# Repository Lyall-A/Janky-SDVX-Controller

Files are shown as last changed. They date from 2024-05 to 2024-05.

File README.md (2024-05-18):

# Janky SDVX Controller
A worse version of the [Pocket-SDVX-Pico-v4](https://github.com/speedypotato/Pocket-SDVX-Pico-v4) with no RGB

## Firmware
* [Leonardo Firmware](./Leonardo%20Firmware): Firmware for ATmega32u4 microcontrollers (Leonardo/Pro Micro)
* [Pico Firmware](./Pico%20Firmware): Firmware for RP2040 microcontrollers (Pico)
* [Unsupported Board Firmware](./Unsupported%20Board%20Firmware): Firmware for other microcontrollers. Uses Serial instead of HID (**PLEASE DO NOT USE THIS**)

## Parts
* x2 Encoders ([PEC16-2015F-N0024](https://mou.sr/3JNRuk8))
* x7 Switches ([Gateron Red](https://mechboards.co.uk/products/gateron-red?variant=41710358888653))
* x1 ATmega32u4 or RP2040 microcontroller ([Raspberry Pi Pico](https://thepihut.com/products/raspberry-pi-pico), [Pro Micro](https://www.aliexpress.com/item/32808519179.html))
* x1 [1U Keycap](https://www.aliexpress.com/item/1005004064331568.html)
* x4 [1.5U Keycaps](https://www.aliexpress.com/item/1005004784994416.html)
* x2 [2U Keycaps](https://www.aliexpress.com/item/1005004784994416.html)

## 3D Printed Parts
* x1 [Case (15mm Thickness)](./Models/STL/Case%20(15mm%20Thickness).stl) or [Case (25mm Thickness)](./Models/STL/Case%20(25mm%20Thickness).stl)
* x1 [Case Top (14.4mm Switch Holes)](./Models/STL/Case%20Top%20(14.4mm%20Switch%20Holes).stl) or [Case Top (14mm Switch Holes)](./Models/STL/Case%20Top%20(14mm%20Switch%20Holes).stl)
* x2 [Knobs (22mm)](./Models/STL/Knob%20(22mm).stl) or [Knobs (25mm)](./Models/STL/Knob%20(25mm).stl)
* x1 [1U Keycap](https://www.printables.com/model/440477-keycaps-for-pico-sdvx-controller)
* x4 [1.5U Keycaps](https://www.printables.com/model/440477-keycaps-for-pico-sdvx-controller)
* x2 [2U Keycaps](https://www.printables.com/model/440477-keycaps-for-pico-sdvx-controller)

## Pictures
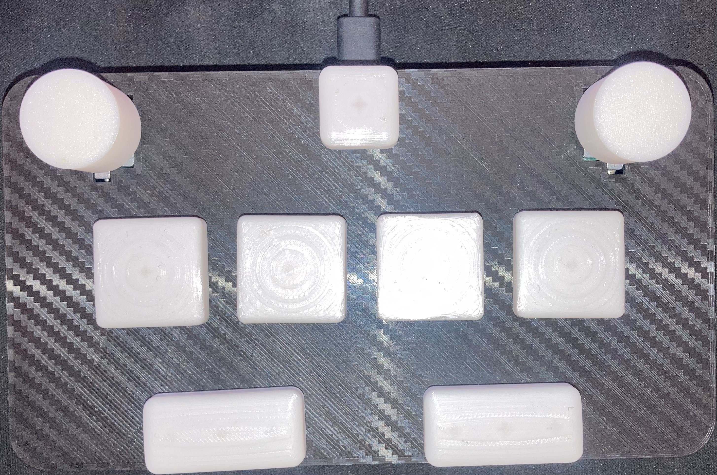
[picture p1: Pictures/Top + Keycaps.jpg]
Top + Keycaps

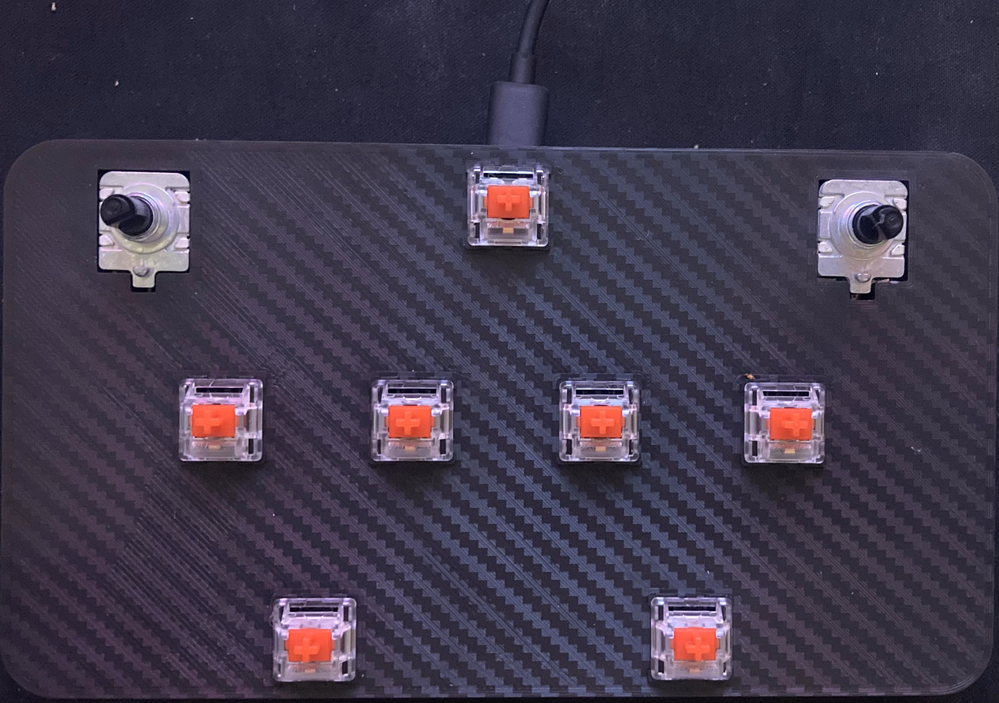
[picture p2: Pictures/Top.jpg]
Top

# DO NOT SCROLL PAST HERE!
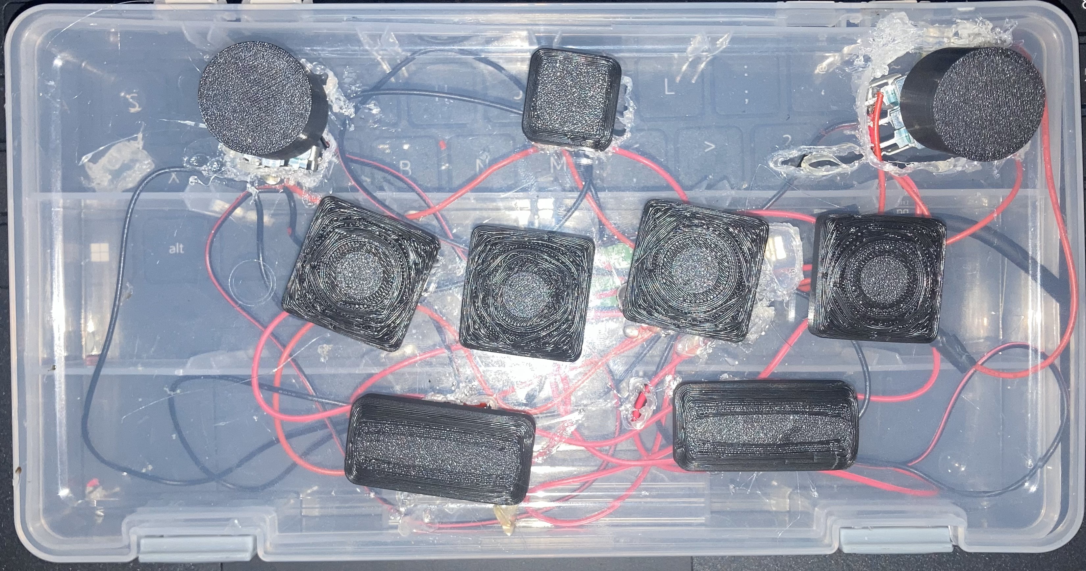
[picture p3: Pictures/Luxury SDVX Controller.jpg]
Luxury SDVX Controller


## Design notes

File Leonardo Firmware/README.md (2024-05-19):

Stolen from https://github.com/speedypotato/Pocket-SDVX

## Flashing the firmware
* Open the `Janky-SDVX-Controller.ino` file in [Arduino IDE](https://www.arduino.cc/en/software)
* Go to `Tools > Board > Arduino AVR Boards` and select `Arduino Leonardo`
* Go to `Tools > Port` and select your port
* Press `Upload` (`CTRL+U`) to compile and upload the firmware to your board

## GPIO
* `4`: BT-A
* `5`: BT-B
* `6`: BT-C
* `7`: BT-D
* `8`: FX-L
* `9`: FX-R
* `21`: START
* `0` & `1`: VOL-L
* `3` & `2`: VOL-R

## Pictures (TODO)
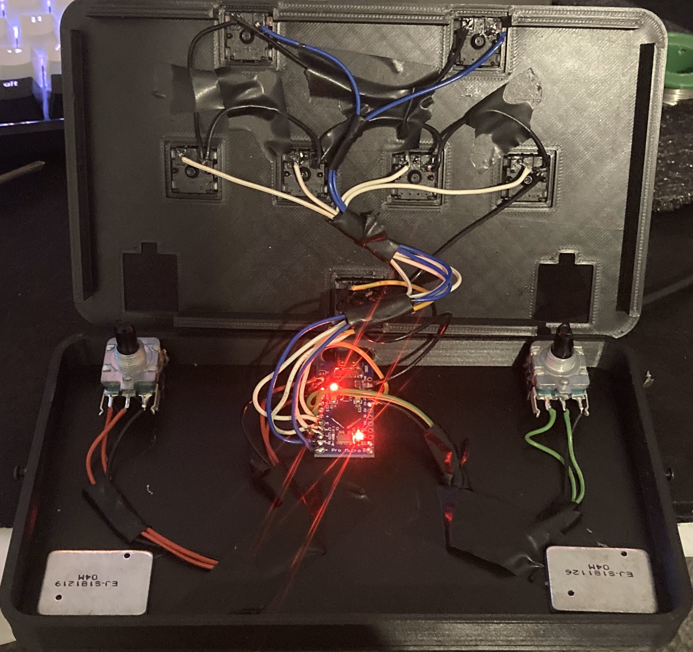
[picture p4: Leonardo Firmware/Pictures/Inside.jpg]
Inside

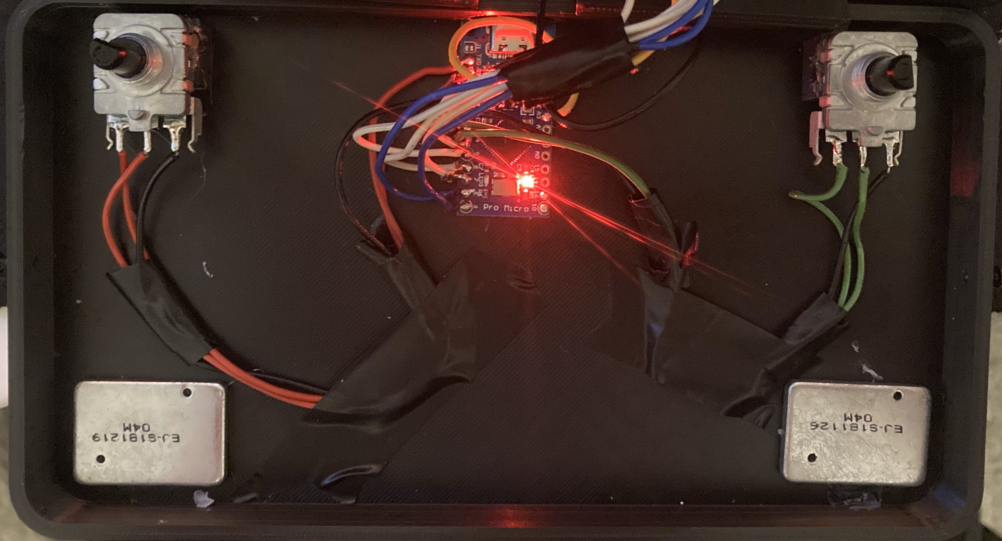
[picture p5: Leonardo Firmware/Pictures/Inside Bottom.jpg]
Inside Bottom

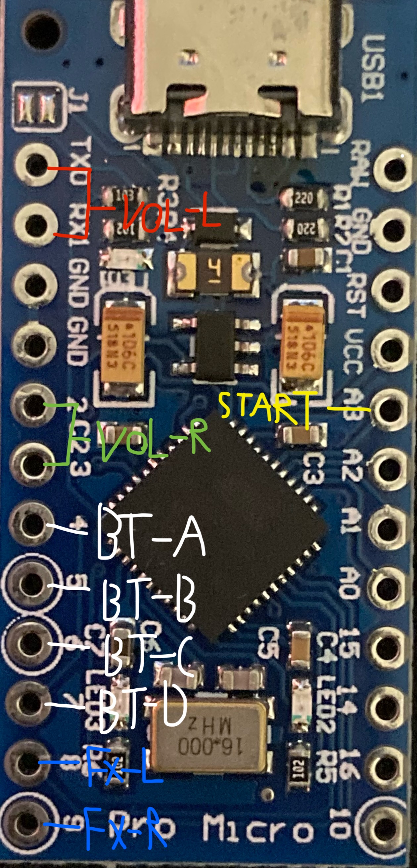
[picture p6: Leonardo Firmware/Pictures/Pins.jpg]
Pins


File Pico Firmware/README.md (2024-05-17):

Stolen from https://github.com/speedypotato/Pocket-SDVX-Pico-v4

## Flashing the firmware
* Hold down the BOOTSEL button while plugging it in
* Drag `Janky-SDVX-Controller.uf2` into the detected drive called RPI-RP2

## GPIO
* `GP2`: BT-A
* `GP3`: BT-B
* `GP4`: BT-C
* `GP5`: BT-D
* `GP8`: FX-L
* `GP9`: FX-R
* `GP6`: START
* `GP14` & `GP15`: VOL-L
* `GP16` & `GP17`: VOL-R

## Pictures
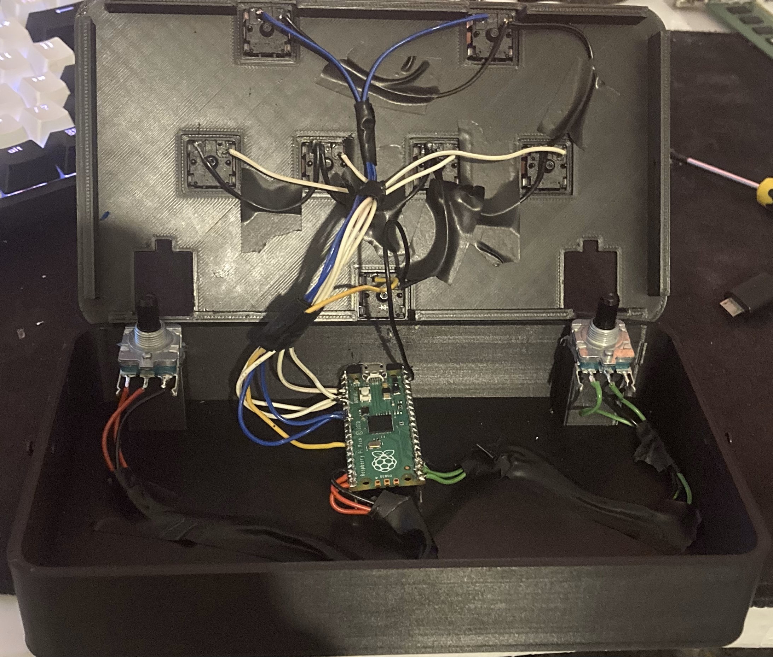
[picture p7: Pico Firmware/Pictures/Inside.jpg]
Inside

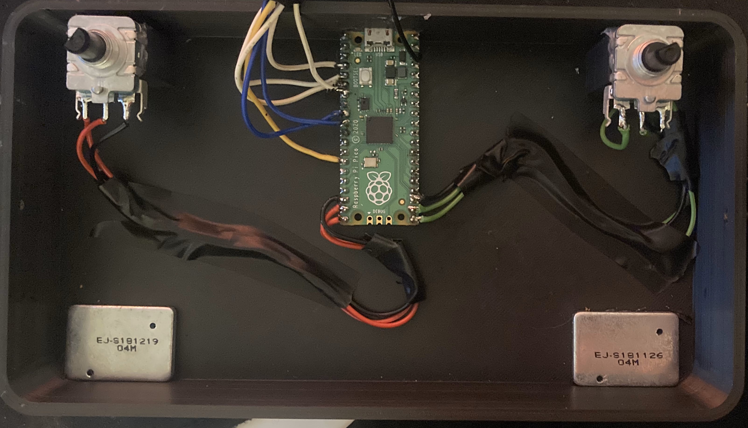
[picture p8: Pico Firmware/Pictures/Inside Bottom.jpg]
Inside Bottom

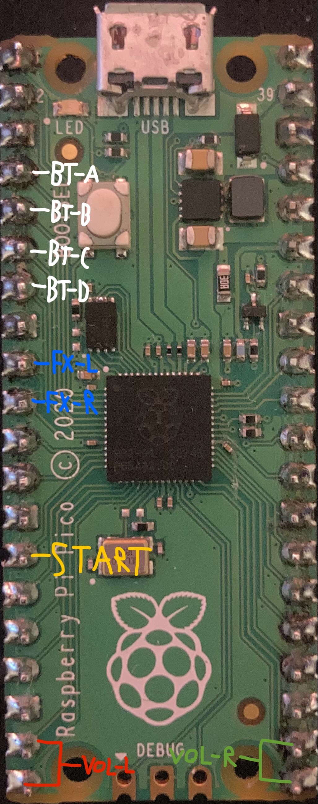
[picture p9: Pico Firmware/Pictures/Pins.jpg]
Pins


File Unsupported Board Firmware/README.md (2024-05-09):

Stolen from https://github.com/speedypotato/Pocket-SDVX

This firmware uses Serial instead of HID and should really **not** be used. This should work with all microcontrollers that can be flashed using Arduino IDE, supports Serial and supports the Arduino Encoder library (has interrupt pins)

## Flashing the firmware
* Open the `Janky-SDVX-Controller.ino` file in [Arduino IDE](https://www.arduino.cc/en/software)
* Modify all the pins
* Go to `Tools > Board` and select your board
* Go to `Tools > Port` and select your port
* Press `Upload` (`CTRL+U`) to compile and upload the firmware to your board
* Run `Start.bat` and input your port and 9600 for baud rate OR run `Serial-To-HID.exe <port> 9600`

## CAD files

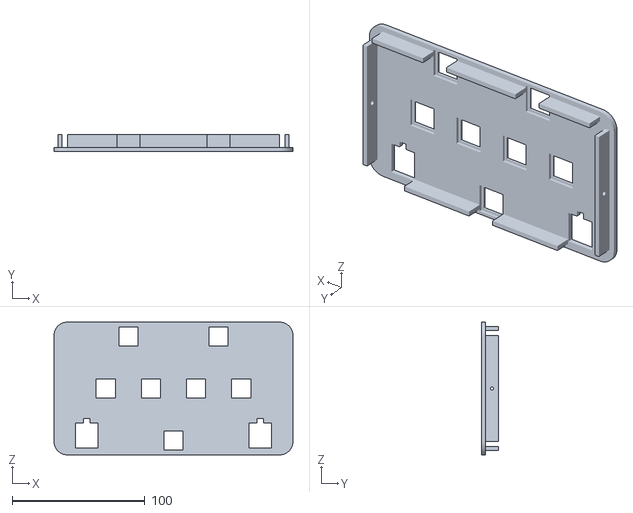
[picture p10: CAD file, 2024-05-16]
Models/STL/Case Top (14.4mm Switch Holes).stl
180.0 x 13.0 x 100.0

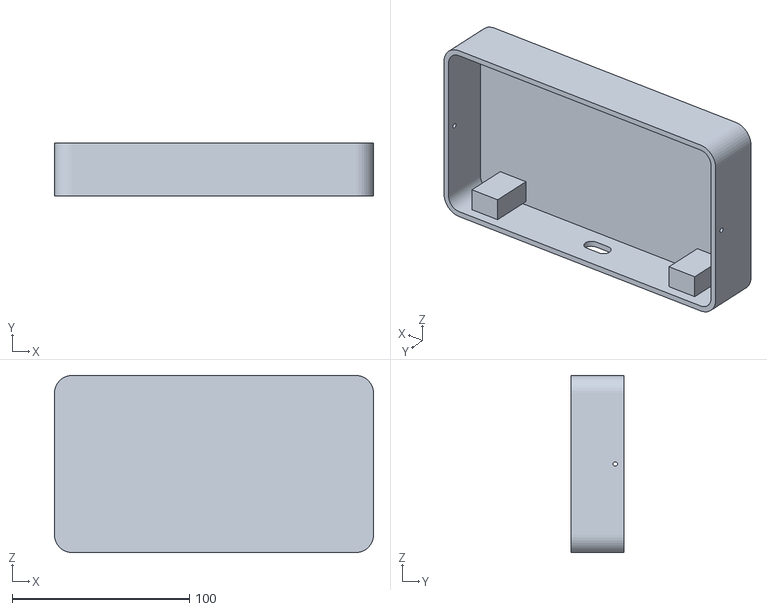
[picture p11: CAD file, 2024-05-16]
Models/STL/Case (30mm Thickness).stl
180.0 x 30.0 x 100.0

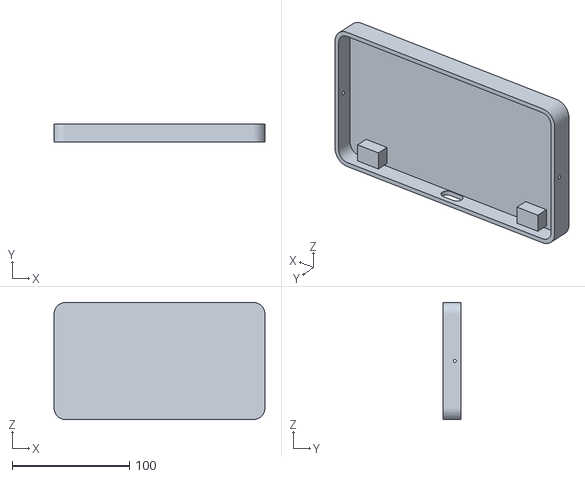
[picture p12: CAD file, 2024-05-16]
Models/STL/Case (15mm Thickness).stl
180.0 x 15.0 x 100.0

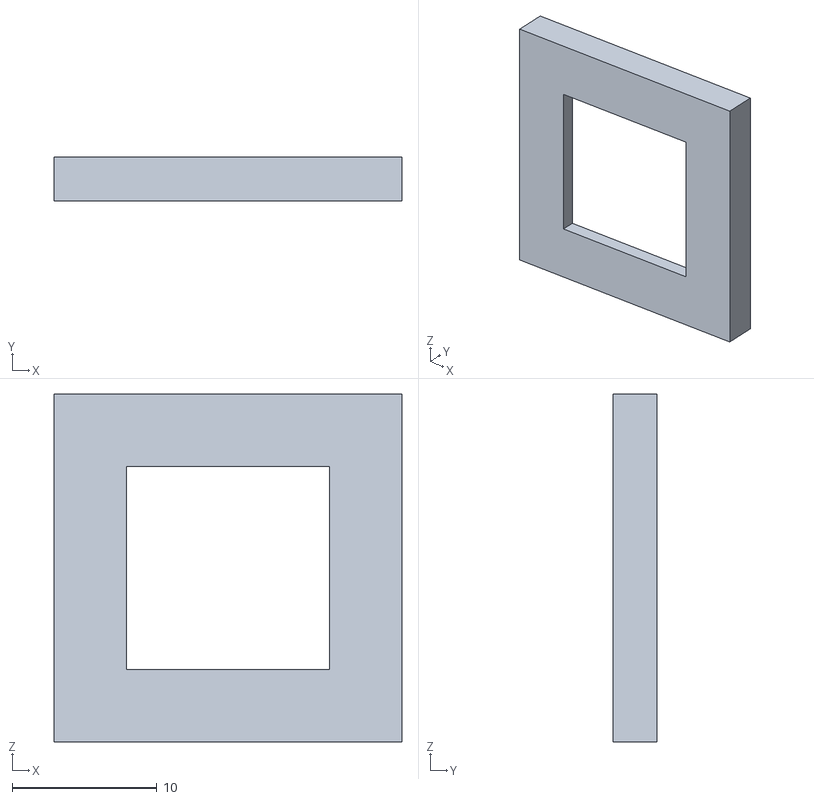
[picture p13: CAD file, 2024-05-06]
Models/STL/Switch Tolerance Test (14mm Switch Hole).stl
24.0 x 3.00 x 24.0

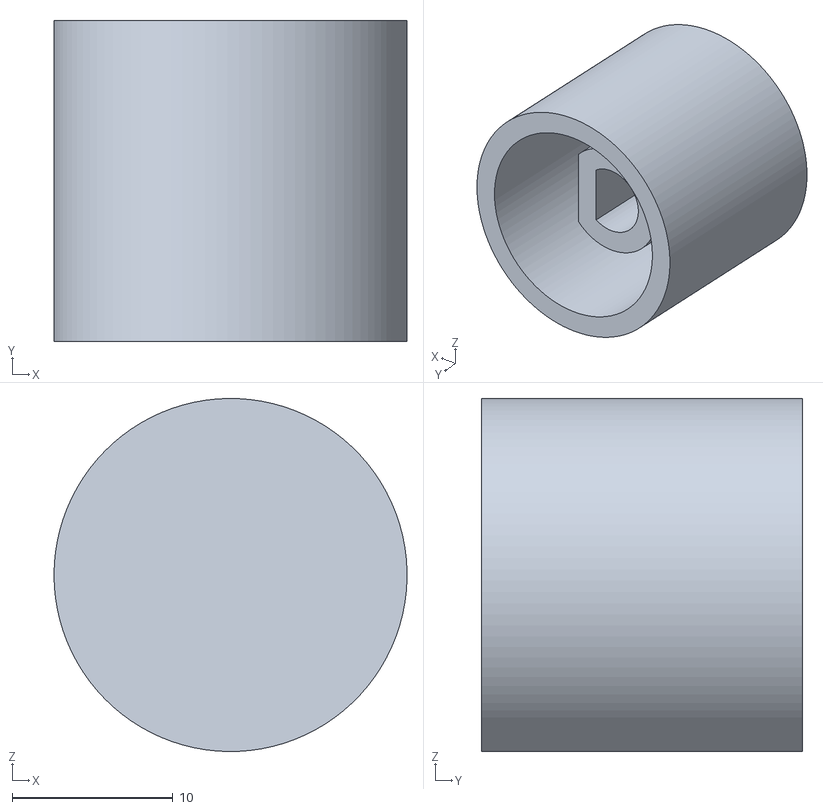
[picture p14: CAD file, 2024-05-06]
Models/STL/Knob (22mm).stl
22.0 x 20.0 x 22.0

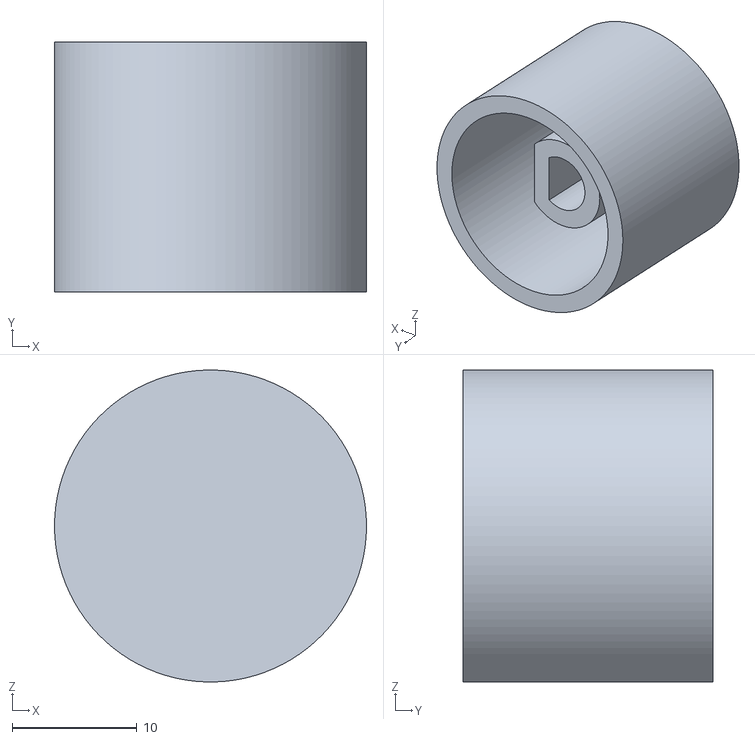
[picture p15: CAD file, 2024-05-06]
Models/STL/Knob (25mm).stl
25.0 x 20.0 x 25.0

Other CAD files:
Models/STL/Case Top (14mm Switch Holes).stl
Models/STL/Switch Tolerance Test (14.4mm Switch Hole).stl
Models/F3D/Case (15mm Thickness).f3d
Models/F3D/Case (30mm Thickness).f3d
Models/F3D/Case Top (14.4mm Switch Holes).f3d
Models/F3D/Case Top (14mm Switch Holes).f3d
Models/F3D/Knob (22mm).f3d
Models/F3D/Knob (25mm).f3d
Models/F3D/Switch Tolerance Test (14.4mm Switch Hole).f3d
Models/F3D/Switch Tolerance Test (14mm Switch Hole).f3d

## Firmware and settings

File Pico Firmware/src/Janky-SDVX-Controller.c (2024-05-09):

/*
 * Pico Game Controller
 * @author SpeedyPotato
 */
#define JANKY_SDVX_CONTROLLER_C

#include <stdio.h>
#include <stdlib.h>
#include <string.h>

// clang-format off
#include "bsp/board.h"
#include "controller_config.h"
#include "types.h"
#include "encoders.pio.h"
#include "hardware/clocks.h"
#include "hardware/dma.h"
#include "hardware/irq.h"
#include "hardware/pio.h"
#include "pico/multicore.h"
#include "pico/stdlib.h"
#include "tusb.h"
#include "usb_descriptors.h"
#include "debounce/debounce_include.h"
// clang-format on

PIO pio, pio_1;
uint32_t enc_val[ENC_GPIO_SIZE];
uint32_t prev_enc_val[ENC_GPIO_SIZE];
int cur_enc_val[ENC_GPIO_SIZE];

bool prev_sw_val[SW_GPIO_SIZE];
uint64_t sw_timestamp[SW_GPIO_SIZE];

bool kbm_report;

void (*loop_mode)();
uint16_t (*debounce_mode)();
bool joy_mode_check = true;

report_t report;

/**
 * Gamepad Mode
 **/
void joy_mode() {
  if (tud_hid_ready()) {
    // find the delta between previous and current enc_val
    for (int i = 0; i < ENC_GPIO_SIZE; i++) {
      cur_enc_val[i] +=
          ((ENC_REV[i] ? 1 : -1) * (enc_val[i] - prev_enc_val[i]));
      while (cur_enc_val[i] < 0) cur_enc_val[i] = ENC_PULSE + cur_enc_val[i];
      cur_enc_val[i] %= ENC_PULSE;

      prev_enc_val[i] = enc_val[i];
    }

    report.joy0 = ((double)cur_enc_val[0] / ENC_PULSE) * (UINT8_MAX + 1);
    report.joy1 = ((double)cur_enc_val[1] / ENC_PULSE) * (UINT8_MAX + 1);

    tud_hid_n_report(0x00, REPORT_ID_JOYSTICK, &report, sizeof(report));
  }
}

/**
 * Keyboard Mode
 **/
void key_mode() {
  if (tud_hid_ready()) {  // Wait for ready, updating mouse too fast hampers
                          // movement
    if (kbm_report) {
      /*------------- Keyboard -------------*/
      uint8_t nkro_report[32] = {0};
      for (int i = 0; i < SW_GPIO_SIZE; i++) {
        if ((report.buttons >> i) % 2 == 1) {
          uint8_t bit = SW_KEYCODE[i] % 8;
          uint8_t byte = (SW_KEYCODE[i] / 8) + 1;
          if (SW_KEYCODE[i] >= 240 && SW_KEYCODE[i] <= 247) {
            nkro_report[0] |= (1 << bit);
          } else if (byte > 0 && byte <= 31) {
            nkro_report[byte] |= (1 << bit);
          }
        }
      }
      tud_hid_n_report(0x00, REPORT_ID_KEYBOARD, &nkro_report,
                       sizeof(nkro_report));
    } else {
      /*------------- Mouse -------------*/
      // find the delta between previous and current enc_val
      int delta[ENC_GPIO_SIZE] = {0};
      for (int i = 0; i < ENC_GPIO_SIZE; i++) {
        delta[i] = (enc_val[i] - prev_enc_val[i]) * (ENC_REV[i] ? 1 : -1);
        prev_enc_val[i] = enc_val[i];
      }

      tud_hid_mouse_report(REPORT_ID_MOUSE, 0x00, delta[0] * MOUSE_SENS,
                           delta[1] * MOUSE_SENS, 0, 0);
    }
    // Alternate reports
    kbm_report = !kbm_report;
  }
}

/**
 * Update Input States
 * Note: Switches are pull up, negate value
 **/
void update_inputs() {
  for (int i = 0; i < SW_GPIO_SIZE; i++) {
    // If switch gets pressed, record timestamp
    if (prev_sw_val[i] == false && !gpio_get(SW_GPIO[i]) == true) {
      sw_timestamp[i] = time_us_64();
    }
    prev_sw_val[i] = !gpio_get(SW_GPIO[i]);
  }
}

/**
 * DMA Encoder Logic For 2 Encoders
 **/
void dma_handler() {
  uint i = 1;
  int interrupt_channel = 0;
  while ((i & dma_hw->ints0) == 0) {
    i = i << 1;
    ++interrupt_channel;
  }
  dma_hw->ints0 = 1u << interrupt_channel;
  if (interrupt_channel < 4) {
    dma_channel_set_read_addr(interrupt_channel, &pio->rxf[interrupt_channel],
                              true);
  }
}

/**
 * Initialize Board Pins
 **/
void init() {
  // LED Pin on when connected
  gpio_init(25);
  gpio_set_dir(25, GPIO_OUT);
  gpio_put(25, 1);

  // Set up the state machine for encoders
  pio = pio0;
  uint offset = pio_add_program(pio, &encoders_program);

  // Setup Encoders
  for (int i = 0; i < ENC_GPIO_SIZE; i++) {
    enc_val[i], prev_enc_val[i], cur_enc_val[i] = 0;
    encoders_program_init(pio, i, offset, ENC_GPIO[i], ENC_DEBOUNCE);

    dma_channel_config c = dma_channel_get_default_config(i);
    channel_config_set_read_increment(&c, false);
    channel_config_set_write_increment(&c, false);
    channel_config_set_dreq(&c, pio_get_dreq(pio, i, false));

    dma_channel_configure(i, &c,
                          &enc_val[i],   // Destination pointer
                          &pio->rxf[i],  // Source pointer
                          0x10,          // Number of transfers
                          true           // Start immediately
    );
    irq_set_exclusive_handler(DMA_IRQ_0, dma_handler);
    irq_set_enabled(DMA_IRQ_0, true);
    dma_channel_set_irq0_enabled(i, true);
  }

  // Setup Button GPIO
  for (int i = 0; i < SW_GPIO_SIZE; i++) {
    prev_sw_val[i] = false;
    sw_timestamp[i] = 0;
    gpio_init(SW_GPIO[i]);
    gpio_set_function(SW_GPIO[i], GPIO_FUNC_SIO);
    gpio_set_dir(SW_GPIO[i], GPIO_IN);
    gpio_pull_up(SW_GPIO[i]);
  }

  // Set listener bools
  kbm_report = false;

  // Joy/KB Mode Switching
  if (!gpio_get(SW_GPIO[0])) {
    loop_mode = &key_mode;
    joy_mode_check = false;
  } else {
    loop_mode = &joy_mode;
    joy_mode_check = true;
  }

  // Debouncing Mode
  debounce_mode = &debounce_eager;
}

/**
 * Main Loop Function
 **/
int main(void) {
  board_init();
  init();
  tusb_init();

  while (1) {
    tud_task();  // tinyusb device task
    update_inputs();
    report.buttons = debounce_mode();
    loop_mode();
  }

  return 0;
}

// Invoked when received GET_REPORT control request
// Application must fill buffer report's content and return its length.
// Return zero will cause the stack to STALL request
uint16_t tud_hid_get_report_cb(uint8_t itf, uint8_t report_id,
                               hid_report_type_t report_type, uint8_t* buffer,
                               uint16_t reqlen) {
  // TODO not Implemented
  (void)itf;
  (void)report_id;
  (void)report_type;
  (void)buffer;
  (void)reqlen;

  return 0;
}

// Invoked when received SET_REPORT control request or
// received data on OUT endpoint ( Report ID = 0, Type = 0 )
void tud_hid_set_report_cb(uint8_t itf, uint8_t report_id,
                           hid_report_type_t report_type, uint8_t const* buffer,
                           uint16_t bufsize) {
  (void)itf;
}

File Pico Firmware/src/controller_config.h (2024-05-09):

#ifndef CONTROLLER_CONFIG_H
#define CONTROLLER_CONFIG_H

#define SW_GPIO_SIZE 7                // Number of switches
#define ENC_GPIO_SIZE 2               // Number of encoders
#define ENC_PPR 24                    // Encoder PPR
#define MOUSE_SENS 5                  // Mouse sensitivity multiplier
#define ENC_DEBOUNCE true             // Encoder Debouncing
#define SW_DEBOUNCE_TIME_US 4000      // Switch debounce delay in us
#define ENC_PULSE (ENC_PPR * 4)       // 4 pulses per PPR

#ifdef JANKY_SDVX_CONTROLLER_C

// MODIFY KEYBINDS HERE, MAKE SURE LENGTHS MATCH SW_GPIO_SIZE
const uint8_t SW_KEYCODE[] = {
    HID_KEY_D, // BT-A
    HID_KEY_F, // BT-B
    HID_KEY_J, // BT-C
    HID_KEY_K, // BT-D
    HID_KEY_C, // FX-L
    HID_KEY_M, // FX-R
    HID_KEY_1, // START
};
const uint8_t SW_GPIO[] = {
    2, // BT-A
    3, // BT-B
    4, // BT-C
    5, // BT-D
    6, // FX-L
    7, // FX-R
    10 // START
};
const uint8_t ENC_GPIO[] = {
    14, // VOL-L
    16, // VOL-R
};
const bool ENC_REV[] = {false, false};  // Reverse Encoders

#endif
extern bool joy_mode_check;
#endif

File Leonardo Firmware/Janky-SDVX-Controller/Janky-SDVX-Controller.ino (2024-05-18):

#include "Janky-SDVX-Controller.h"
#include "Encoder.h"
#include "Keyboard.h"
#include "Mouse.h"
#include <EEPROM.h>

JankySDVXControllerReport_t report;

// Number of microseconds between HID reports
// 2000 = 500hz
#define REPORT_DELAY 1000

// Read eeprom address 0. Value stored indicated mode. Mode1=joystick, Mode2=keyboard.
int currMode = EEPROM.read(0);

// Mouse Sens Multiplier
#define MOUSE_MULT  3

// Button Keybinds
#define BIND_A    'd'
#define BIND_B    'f'
#define BIND_C    'j'
#define BIND_D    'k'
#define BIND_FX_L 'c'
#define BIND_FX_R 'm'
#define BIND_ST   '1'

// Button Pinout
#define BT_A  4
#define BT_B  5
#define BT_C  6
#define BT_D  7
#define FX_L  8
#define FX_R  9
#define BT_ST 21

// Number of cycles before HID falls back to reactive
unsigned long reactiveTimeoutMax = 1000;
unsigned long reactiveTimeoutCount = reactiveTimeoutMax;

uint8_t bindKeys[] = { BIND_A, BIND_B, BIND_C, BIND_D, BIND_FX_L, BIND_FX_R, BIND_ST };
uint8_t buttonPins[] = { BT_A, BT_B, BT_C, BT_D, FX_L, FX_R, BT_ST };
uint8_t buttonCount = sizeof(buttonPins) / sizeof(buttonPins[0]);

// Encoder sensitivity = number of positions per rotation times 4 (24*4) / number of positions for HID report (256)
#define ENCODER_SENSITIVITY (double) 0.375
Encoder encL(0, 1), encR(3, 2);
float knob1 = 0;
float knob2 = 0;
float old_knob1 = 0;
float old_knob2 = 0;

/**
 * Arduino Setup
 */
void setup() {
  // Setup I/O for pins
  for (int i = 0; i < buttonCount; i++) {
    pinMode(buttonPins[i], INPUT_PULLUP);
  }

  // Startup mode
  int Button1State = digitalRead(BT_A); //Read Btn-A
  int Button2State = digitalRead(BT_B); //Read Btn-B
  // Button 1 is held down: Joystick Mode
  if (Button1State == LOW && Button2State == HIGH) {
    if (currMode != 1) {
      EEPROM.update(0, 1); 
      delay(200);
    }
  } else if (Button2State == LOW && Button1State == HIGH) {
    // Button 2 is held down: Keyboard Mode
    if (currMode != 2) {
      EEPROM.update(0, 2);
      delay(200);
    }
  }
}

/**
 * Arduino Loop
 */
void loop() {
  if (EEPROM.read(0) == 1) {
    joy_mode();
  } else if (EEPROM.read(0) == 2) {
    keyboard_mode();
  }
}

/**
 * Keyboard Implementation
 */
void keyboard_mode() {
  // Read encoders
  knob1 =  (float)(encL.read());
  knob2 = (float)encR.read();

  if(knob1 != old_knob1) {
    Mouse.move((knob1 - old_knob1) * MOUSE_MULT, 0);
    
    // We count the difference in the encoders, but we must not go over arduino's int limit
    if(knob1 < -255 || knob1 > 255) {
      encL.write(0);
      old_knob1 = 0;
    } else {
      old_knob1 = knob1;
    }
  }
  
  if(knob2 != old_knob2) {
    Mouse.move(0, (knob2 - old_knob2) * MOUSE_MULT);
    
    if(knob2 < -255 || knob2 > 255) {
      encR.write(0);
      old_knob2 = 0;
    } else {
      old_knob2 = knob2;
    }
  }
  
  // Read the buttons, if it's low, output a keyboard press  
  for (int i = 0; i < buttonCount; i++) {
    if (digitalRead(buttonPins[i]) == LOW) {
      Keyboard.press(bindKeys[i]);
    } else {
      Keyboard.release(bindKeys[i]);
    }
  }
}

/**
 * Controller Implementation
 */
void joy_mode() {
  // Read buttons except BT_ST
  for (int i = 0; i < buttonCount - 1; i++) {
    if (digitalRead(buttonPins[i]) != HIGH) {
      report.buttons |= (uint16_t)1 << i;
    } else {
      report.buttons &= ~((uint16_t)1 << i);
    }
  }
  // Read BT_ST
  if (digitalRead(BT_ST) != HIGH) {
    report.buttons |= (uint16_t)1 << 8;
  } else {
    report.buttons &= ~((uint16_t)1 << 8);
  }
  
  // Read Encoders
  report.xAxis = (uint8_t)((int32_t)(encL.read() / ENCODER_SENSITIVITY) % 256);
  report.yAxis = (uint8_t)((int32_t)(encR.read() / ENCODER_SENSITIVITY) % 256);
  
  JankySDVXController.setState(&report);
  delayMicroseconds(REPORT_DELAY);
}

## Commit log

2024-05-05 pico gpio
2024-05-06 model update
    [Case (INCOMPLETE).f3d, Case (INCOMPLETE).stl, Case Top (INCOMPLETE).f3d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]
2024-05-06 untested models, low chance of being final
    [Case Top (INCOMPLETE).f3d, Case Top (INCOMPLETE).stl, Case Top.f3d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]
2024-05-06 fix knobs
    [Knob (22mm).f3d, Knob (22mm).stl, Knob (25mm).f3d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]
2024-05-06 WORKING knobs
    [Knob (22mm).f3d, Knob (22mm).stl, Knob (25mm).f3d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]
2024-05-06 14mm tolerance test
    [Switch Tolerance Test (14.4mm, 1.3mm).f3d, Switch Tolerance Test (14mm, 1.3mm).f3d, Switch Tolerance Test (14mm, 1.3mm).stl]
2024-05-06 14mm case top
    [Case Top (14.4mm).f3d, Case Top (14.4mm).stl, Case Top (14mm).f3d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]
2024-05-06 readme and file name changes
    [Case Top (14.4mm Switch Holes).f3d, Case Top (14.4mm Switch Holes).stl, Case Top (14mm Switch Holes).f3d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]
2024-05-06 case top edits (mostly FX btn spacing)
    [Case Top (14.4mm Switch Holes).f3d, Case Top (14.4mm Switch Holes).stl, Case Top (14mm Switch Holes).f3d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]
2024-05-06 fix fuckup
    [Case Top (14.4mm Switch Holes).f3d, Case Top (14.4mm Switch Holes).stl, Case Top (14mm Switch Holes).f3d]
2024-05-07 FINAL CASE! fixed tab cutout for encoders and changed port size
    [Case Top (14.4mm Switch Holes).f3d, Case Top (14.4mm Switch Holes).stl, Case Top (14mm Switch Holes).f3d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]
2024-05-08 FIX: Remove tabs next to encoders and change FX-L and FX-R GPIO
    [Case Top (14.4mm Switch Holes).f3d, Case Top (14.4mm Switch Holes).stl, Case Top (14mm Switch Holes).f3d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]
2024-05-09 organise models
    [Case Top (14.4mm Switch Holes).f3d, Case Top (14.4mm Switch Holes).stl, Case Top (14mm Switch Holes).f3d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]
2024-05-16 added 15mm case thickness and changed case top tabs
    [Case (15mm Thickness).f3d, Case (15mm Thickness).stl, Case (30mm Thickness).f3d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]
2024-05-18 fix readme and leonardo firmware
    [Janky-SDVX-Controller.ino]
